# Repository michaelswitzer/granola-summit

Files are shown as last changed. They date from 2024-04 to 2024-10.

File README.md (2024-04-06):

# Summit by Granola Arcade

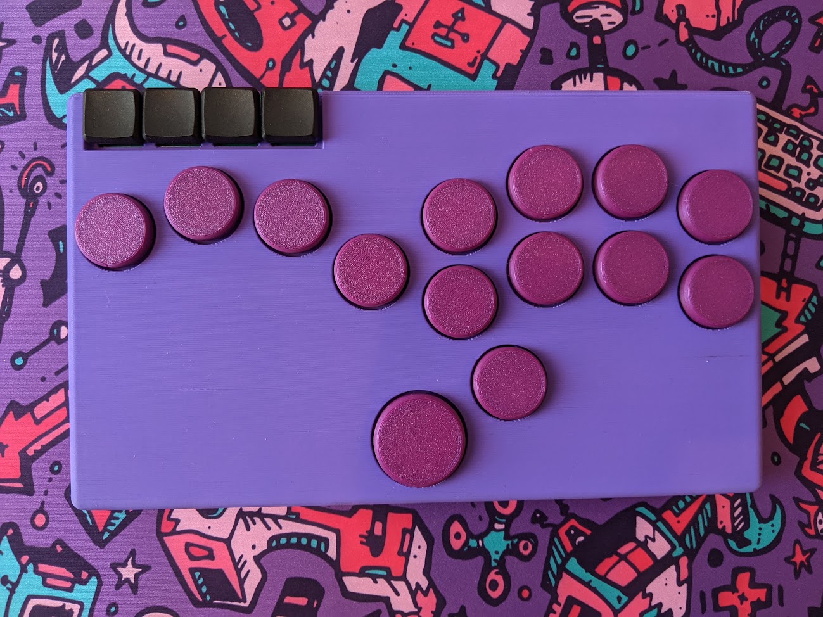
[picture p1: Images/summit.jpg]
Summit fightstick


The Summit is a button box style arcade controller by Granola Arcade.

You can buy the Summit at https://granola.games

## License
The Raindrop is licensed under a <a rel="license" href="http://creativecommons.org/licenses/by-nc-sa/4.0/">Creative Commons Attribution-NonCommercial-ShareAlike 4.0 International License</a>. In simple terms, this means you are welcome to use or remix these designs to build your own controller free of cost. You are *not* permitted to sell the Summit commercially. You also can't republish the designs without attribution and without carrying this license forward into your new designs. For more information see the license file in this repository.

## How to build
To build your own Summit, import the PCB designs and bill of materials using KiCAD. I provided a list of parts that use JLCPCB's part assembly services, since that is the company I use to manufacture the PCB. You can use these files as a starting point for building your own PCB.

The .step file for the case is optimized for FDM 3D printers. I recommend PLA with at least 15% infill but you can use any material you wish. The case has designed break-away supports that you will remove after printing. It should already be aligned in the correct orientation.

The keycap files are also included, for use with Kailh Choc V2 stems (MX style). You may need to adjust the x-y hole and contour compensation values in your slicer for proper fitment.

You will need to source your own key switches. The Summit uses Kailh low-profile Choc keyboard switches.

Once you have the case, switches and keycaps, you simply slide the PCB into the top of the case and then attach the switches and keycaps to assemble. Then plug the controller into your PC and upload the firmware.

## Firmware
The Summit is designed to use the <a rel="GP2040-CE firmware" href="https://github.com/OpenStickCommunity/GP2040-CE">GP2040-CE firmware</a>.

## Credits
The Raindrop was designed by Michael Switzer. The GP2040-CE firmware is maintained by <a href="https://github.com/OpenStickCommunity">OpenStickCommunity</a>. This project was inspired by the <a href="https://github.com/jfedor2/flatbox">Flatbox</a>.

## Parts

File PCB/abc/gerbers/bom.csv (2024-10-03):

Comment | Designator | Footprint | LCSC Part Number
10uF | C1,C2 | Capacitor_SMD:C_0805_2012Metric | C83061
27p | C3,C4 | Capacitor_SMD:C_0402_1005Metric | C147436
100nF | C5,C6,C7,C9,C11,C12,C13,C14,C15,C16 | Capacitor_SMD:C_0402_1005Metric | C361203
1uF | C8,C10 | Capacitor_SMD:C_0402_1005Metric | C5137485
10uF | C17 | Capacitor_SMD:C_0805_2012Metric | C83061
HRO-TYPE-C-31-M-12 | USB1 | Type-C:HRO-TYPE-C-31-M-12-Assembly | C165948
USB_A | USB2 | USB-A-SMD_C42591 | C42591
1k | R1,R4 | Capacitor_SMD:C_0402_1005Metric | C105637
5.1k | R5,R6 | Resistor_SMD:R_0402_1005Metric | C25905
27 ohm | R2,R3 | Capacitor_SMD:C_0402_1005Metric | C2909343
TS-1187A-B-A-B | SW1 | Button_Switch_SMD:SW_Push_1P1T_XKB_TS-1187A | C318884
MX_Switch | SW2,SW3,SW4,SW5,SW6,SW7,SW8,SW9,SW10,SW11,SW12,SW13,SW14,SW15,SW16,SW17,SW18,SW19 | Kailh:SW_Hotswap_Kailh_Choc_V1V2_1.00u_reversible,Kailh:SW_Hotswap_Kailh_Choc_V1V2_1.00u_24mm_reversible,Kailh:SW_Hotswap_Kailh_Choc_V1V2_1.00u_30mm_reversible | C5333465
AMS1117 | U1 | Package_TO_SOT_SMD:SOT-223-3_TabPin2 | C5250992
W25Q128JVS | U2 | Package_SO:SOIC-8_5.23x5.23mm_P1.27mm | C97521
RP2040 | U3 | RP2040_minimal:RP2040-QFN-56 | C2040
USBLC6-2SC6 | U4 | Package_TO_SOT_SMD:SOT-23-6 | C5250994
Crystal_GND24 | Y1 | Crystal:Crystal_SMD_3225-4Pin_3.2x2.5mm | C9002
AudioJack3 | J1,J2,J3 | Connector_Audio:Jack_3.5mm_PJ320D_Horizontal | C431535

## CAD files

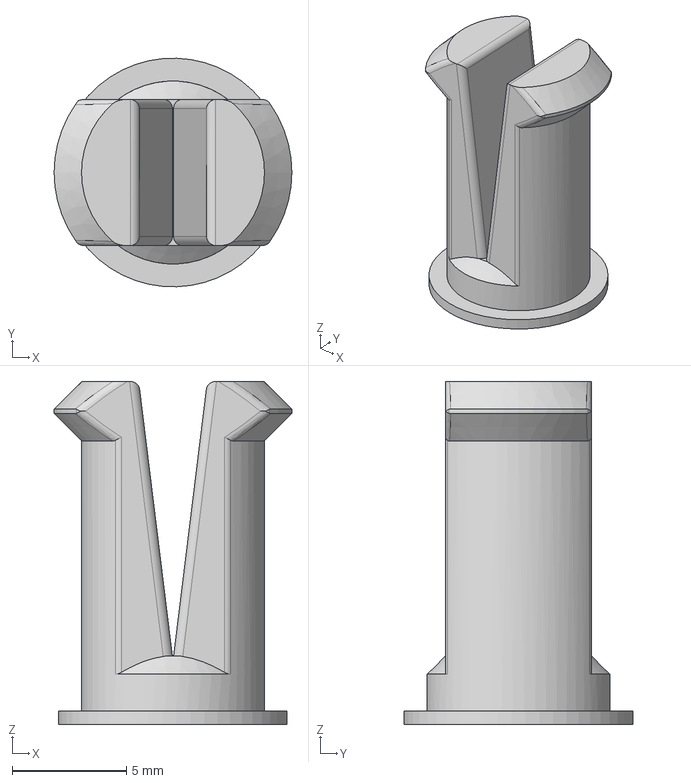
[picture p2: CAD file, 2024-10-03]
Printer/ArtCase-peg.step
10.4 x 10.00 x 15.0 mm

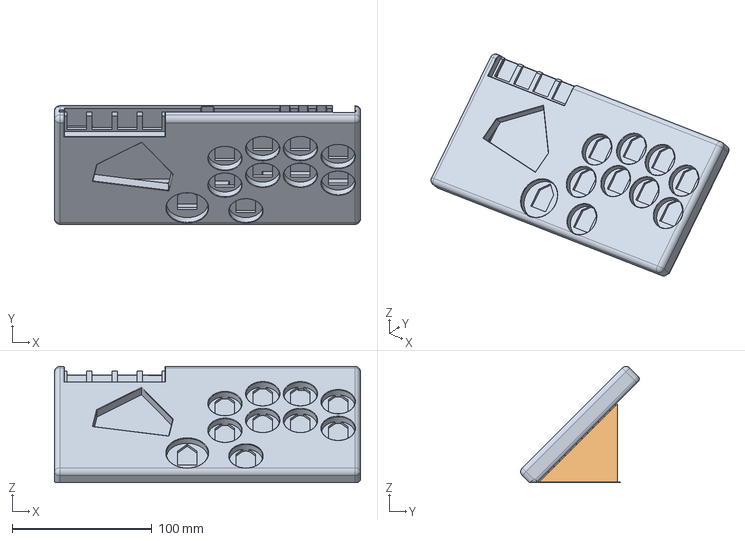
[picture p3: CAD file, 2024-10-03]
Printer/Wasd-case.step
219.0 x 84.9 x 83.2 mm

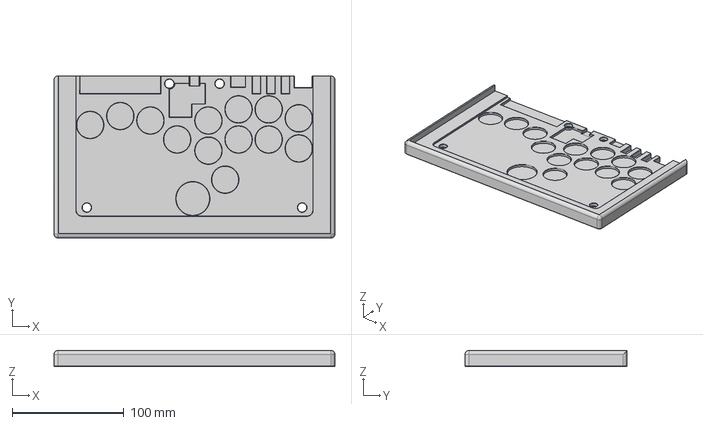
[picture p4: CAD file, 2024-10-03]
Printer/ArtCase-case.step
251.8 x 145.4 x 14.4 mm

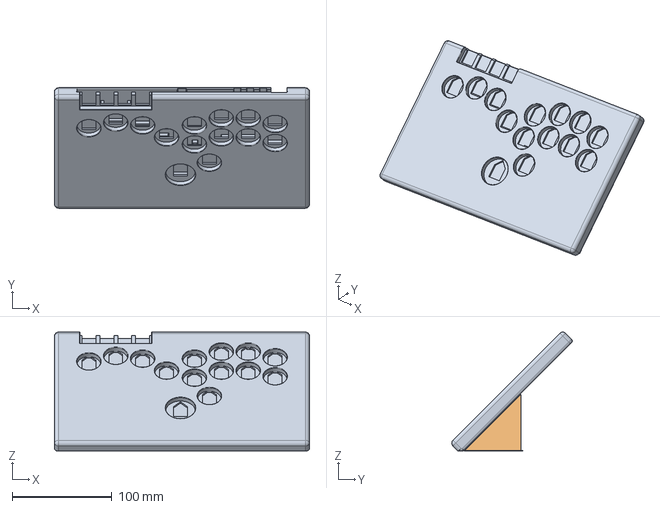
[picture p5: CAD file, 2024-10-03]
Printer/Summit-big-case.step
256.0 x 121.0 x 119.3 mm

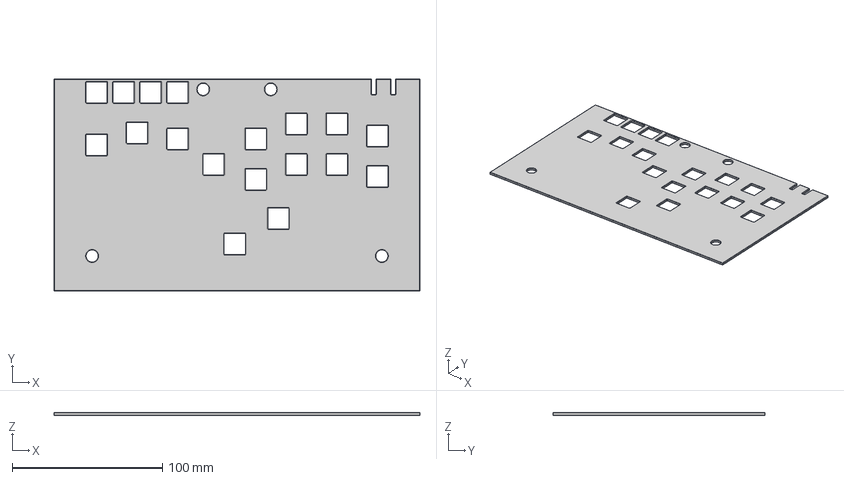
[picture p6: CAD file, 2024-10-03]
Printer/ArtCase-plate.step
243.8 x 141.4 x 2.00 mm

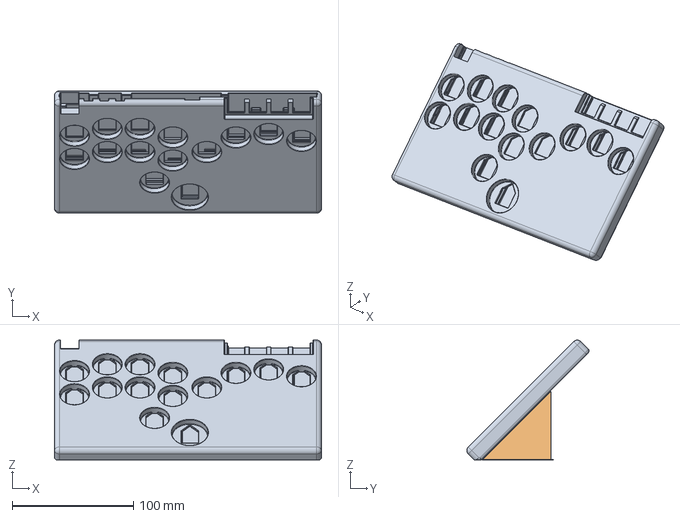
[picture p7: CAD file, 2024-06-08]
Printer/Southpaw-Summit-case.step
220.0 x 100.7 x 98.7 mm

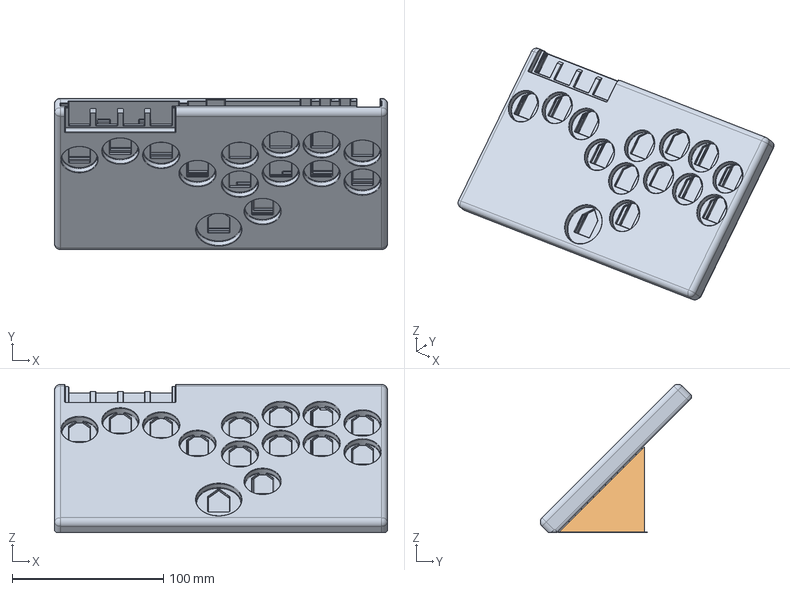
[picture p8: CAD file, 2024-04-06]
Printer/Summit-case.step
220.0 x 100.0 x 98.0 mm

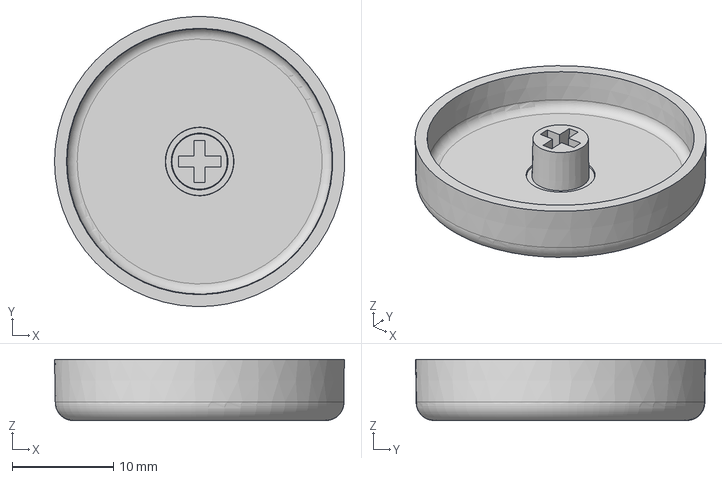
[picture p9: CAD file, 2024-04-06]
Printer/ButtonCap-30mm.step
28.6 x 28.6 x 6.02 mm

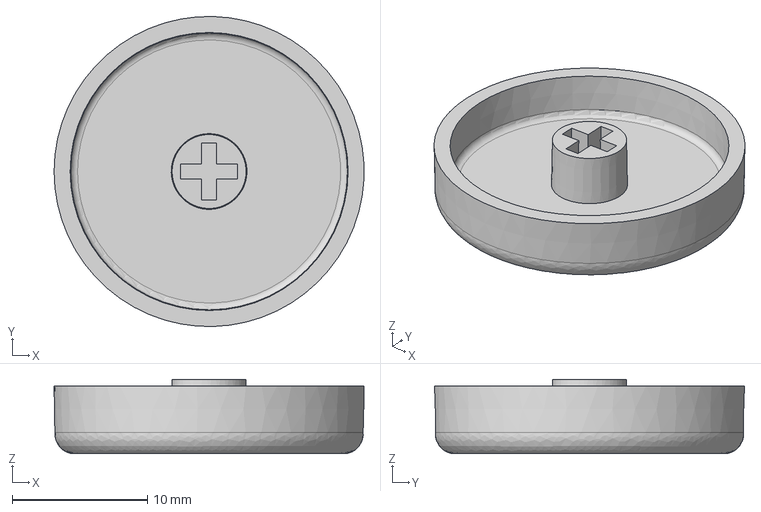
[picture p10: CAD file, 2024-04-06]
Printer/ButtonCap-24mm.step
22.9 x 22.9 x 5.50 mm

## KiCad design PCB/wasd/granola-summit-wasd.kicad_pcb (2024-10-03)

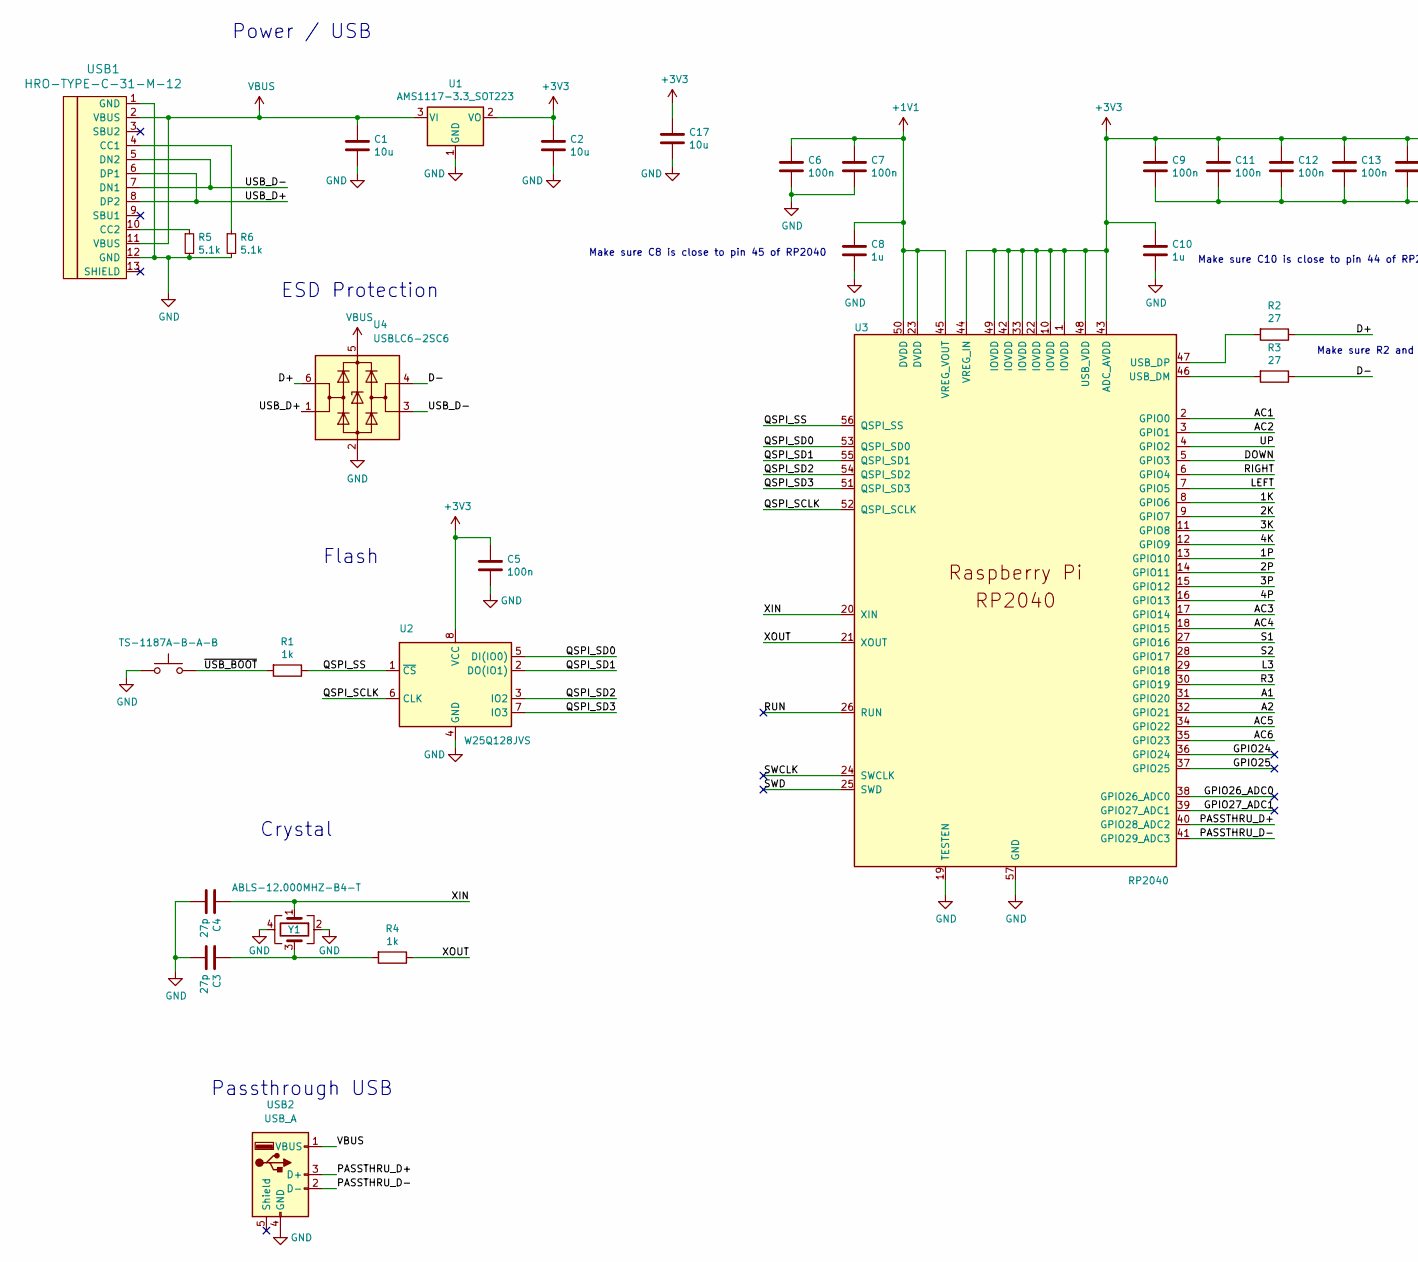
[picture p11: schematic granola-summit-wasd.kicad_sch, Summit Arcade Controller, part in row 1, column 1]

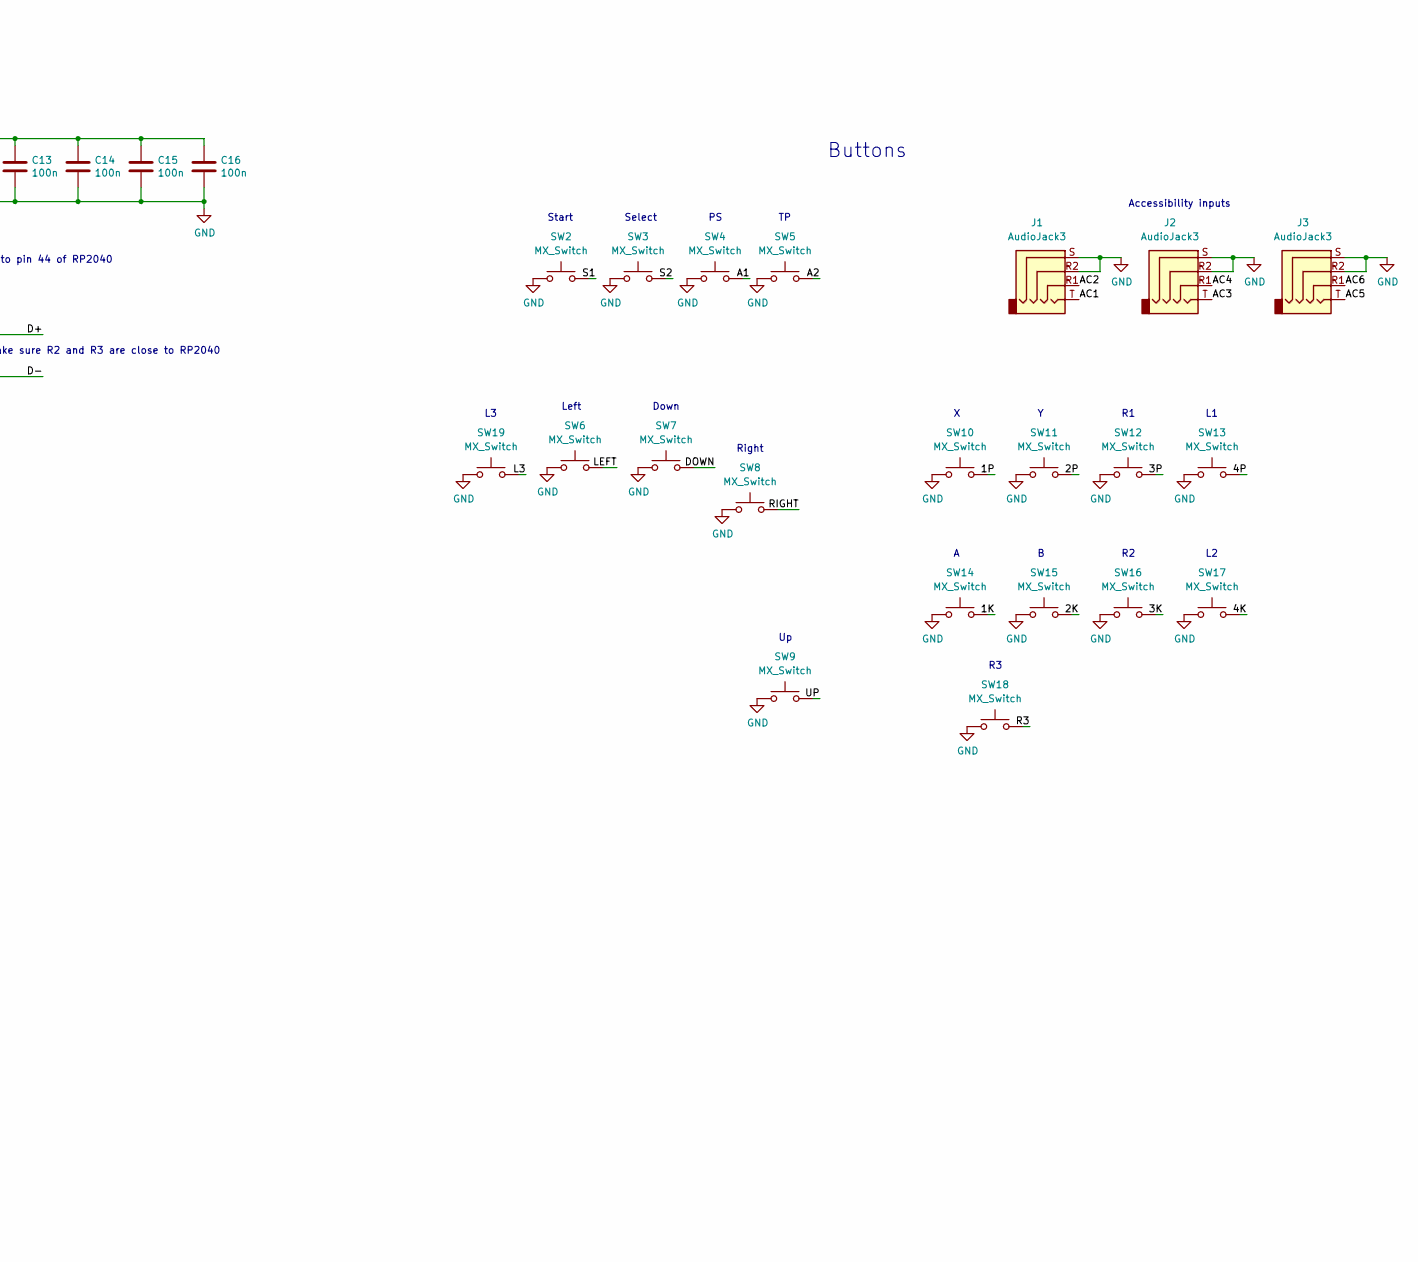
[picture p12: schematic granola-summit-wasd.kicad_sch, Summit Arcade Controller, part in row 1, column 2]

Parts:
C1, C2, C17: 10u; C_0805_2012Metric; LCSC C83061
C3, C4: 27p; C_0402_1005Metric; LCSC C147436
C5, C6, C7, C9, C11, C12, C13, C14, C15, C16: 100n; C_0402_1005Metric; LCSC C115671
C8, C10: 1u; C_0402_1005Metric; LCSC C5137485
J1, J2, J3: AudioJack3; Jack_3.5mm_PJ320D_Horizontal
R1, R4: 1k; C_0402_1005Metric; LCSC C105637
R2, R3: 27; C_0402_1005Metric; LCSC C2909343
R5, R6: 5.1k; R_0402_1005Metric; LCSC C25905
SW1: TS-1187A-B-A-B; SW_Push_1P1T_XKB_TS-1187A; LCSC C318884
SW2, SW3, SW4, SW5, SW6, SW7, SW8, SW9, SW10, SW11, SW12, SW13, SW14, SW15, SW16, SW17, SW18, SW19: MX_Switch; SW_Hotswap_Kailh_Choc_V1V2_1.00u
U1: AMS1117-3.3_SOT223; SOT-223-3_TabPin2; LCSC C5250992
U2: W25Q128JVS; SOIC-8_5.23x5.23mm_P1.27mm; LCSC C97521
U3: RP2040; RP2040-QFN-56; LCSC C2040
U4: USBLC6-2SC6; SOT-23-6
USB1: HRO-TYPE-C-31-M-12; HRO-TYPE-C-31-M-12-Assembly; LCSC C165948
USB2: USB_A; USB-A-SMD_C42591; LCSC C42591
Y1: ABLS-12.000MHZ-B4-T; Crystal_SMD_3225-4Pin_3.2x2.5mm; LCSC C9002

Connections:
+1V1: C6.1, C7.1, C8.1, U3.23 (DVDD), U3.45 (VREG_VOUT), U3.50 (DVDD)
+3V3: C2.1, C5.1, C9.1, C10.1, C11.1, C12.1, C13.1, C14.1, C15.1, C16.1, C17.1, U1.2 (VO), U2.8 (VCC), U3.1 (IOVDD), U3.10 (IOVDD), U3.22 (IOVDD), U3.33 (IOVDD), U3.42 (IOVDD), U3.43 (ADC_AVDD), U3.44 (VREG_IN), U3.48 (USB_VDD), U3.49 (IOVDD)
/1K: SW14.1 (A), U3.8 (GPIO6)
/1P: SW10.1 (A), U3.13 (GPIO10)
/2K: SW15.1 (A), U3.9 (GPIO7)
/2P: SW11.1 (A), U3.14 (GPIO11)
/3K: SW16.1 (A), U3.11 (GPIO8)
/3P: SW12.1 (A), U3.15 (GPIO12)
/4K: SW17.1 (A), U3.12 (GPIO9)
/4P: SW13.1 (A), U3.16 (GPIO13)
/A1: SW4.1 (A), U3.31 (GPIO20)
/A2: SW5.1 (A), U3.32 (GPIO21)
/AC1: J1.T, U3.2 (GPIO0)
/AC2: J1.R1, U3.3 (GPIO1)
/AC3: J2.T, U3.17 (GPIO14)
/AC4: J2.R1, U3.18 (GPIO15)
/AC5: J3.T, U3.34 (GPIO22)
/AC6: J3.R1, U3.35 (GPIO23)
/D+: R2.1, U4.6 (I/O1)
/D-: R3.1, U4.4 (I/O2)
/DOWN: SW7.1 (A), U3.5 (GPIO3)
/GPIO24: U3.36 (GPIO24)
/GPIO25: U3.37 (GPIO25)
/GPIO26_ADC0: U3.38 (GPIO26_ADC0)
/GPIO27_ADC1: U3.39 (GPIO27_ADC1)
/L3: SW19.1 (A), U3.29 (GPIO18)
/LEFT: SW6.1 (A), U3.7 (GPIO5)
/PASSTHRU_D+: U3.40 (GPIO28_ADC2), USB2.3 (D+)
/PASSTHRU_D-: U3.41 (GPIO29_ADC3), USB2.2 (D-)
/QSPI_SCLK: U2.6 (CLK), U3.52 (QSPI_SCLK)
/QSPI_SD0: U2.5 (DI(IO0)), U3.53 (QSPI_SD0)
/QSPI_SD1: U2.2 (DO(IO1)), U3.55 (QSPI_SD1)
/QSPI_SD2: U2.3 (IO2), U3.54 (QSPI_SD2)
/QSPI_SD3: U2.7 (IO3), U3.51 (QSPI_SD3)
/QSPI_SS: R1.1, U2.1 (~CS), U3.56 (QSPI_SS)
/R3: SW18.1 (A), U3.30 (GPIO19)
/RIGHT: SW8.1 (A), U3.6 (GPIO4)
/RUN: U3.26 (RUN)
/S1: SW2.1 (A), U3.27 (GPIO16)
/S2: SW3.1 (A), U3.28 (GPIO17)
/SWCLK: U3.24 (SWCLK)
/SWD: U3.25 (SWD)
/UP: SW9.1 (A), U3.4 (GPIO2)
/USB_D+: U4.1 (I/O1), USB1.6 (DP1), USB1.8 (DP2)
/USB_D-: U4.3 (I/O2), USB1.5 (DN2), USB1.7 (DN1)
/XIN: C4.1, U3.20 (XIN), Y1.1
/XOUT: R4.1, U3.21 (XOUT)
/~USB_BOOT: R1.2, SW1.1
GND: C1.2, C2.2, C3.2, C4.2, C5.2, C6.2, C7.2, C8.2, C9.2, C10.2, C11.2, C12.2, C13.2, C14.2, C15.2, C16.2, C17.2, J1.R2, J1.S, J2.R2, J2.S, J3.R2, J3.S, R5.2, R6.2, SW1.2, SW2.2 (B), SW3.2 (B), SW4.2 (B), SW5.2 (B), SW6.2 (B), SW7.2 (B), SW8.2 (B), SW9.2 (B), SW10.2 (B), SW11.2 (B), SW12.2 (B), SW13.2 (B), SW14.2 (B), SW15.2 (B), SW16.2 (B), SW17.2 (B), SW18.2 (B), SW19.2 (B), U1.1 (GND), U2.4 (GND), U3.19 (TESTEN), U3.57 (GND), U4.2 (GND), USB1.1 (GND), USB1.12 (GND), USB2.4 (GND), Y1.2, Y1.4
unnamed: C3.1, R4.2, Y1.3
unnamed: R3.2, U3.46 (USB_DM)
unnamed: R2.2, U3.47 (USB_DP)
unnamed: R6.1, USB1.4 (CC1)
unnamed: R5.1, USB1.10 (CC2)
VBUS: C1.1, U1.3 (VI), U4.5 (VBUS), USB1.2 (VBUS), USB1.11 (VBUS), USB2.1 (VBUS)

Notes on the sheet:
ESD Protection
Right
Start
Down
Left
Make sure R2 and R3 are close to RP2040
Crystal
Passthrough USB
Make sure C10 is close to pin 44 of RP2040
Flash
Accessibility inputs
Power / USB
Select
Buttons
Make sure C8 is close to pin 45 of RP2040

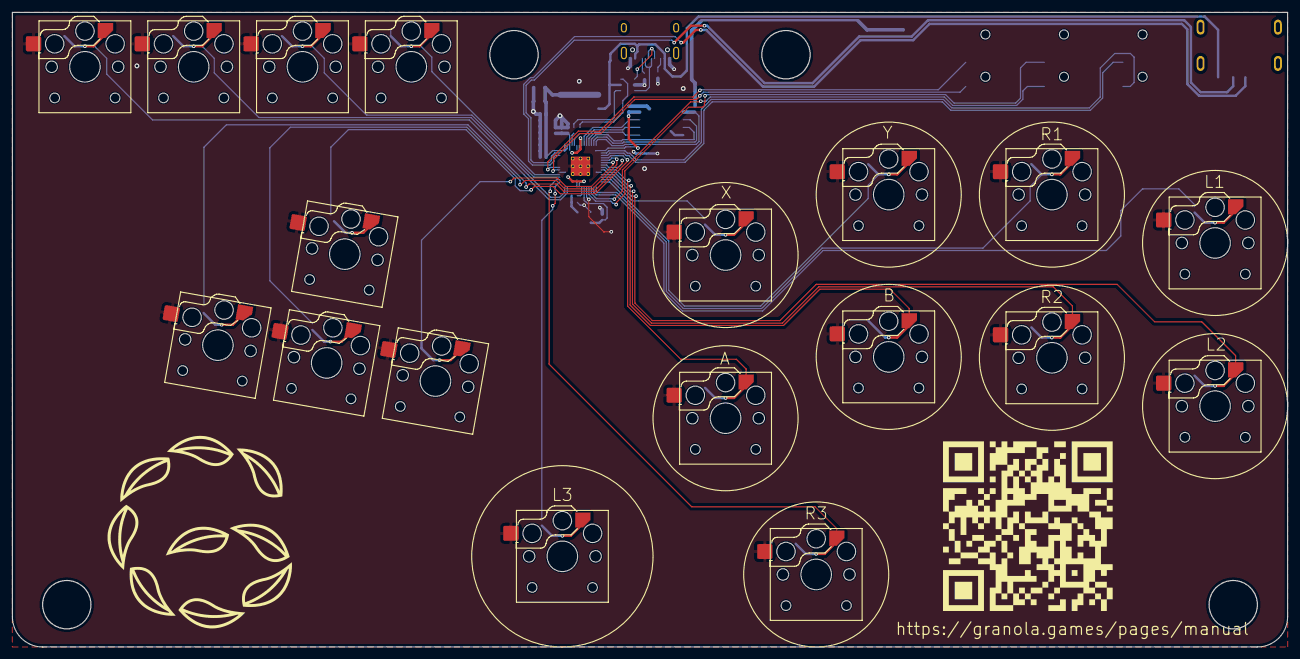
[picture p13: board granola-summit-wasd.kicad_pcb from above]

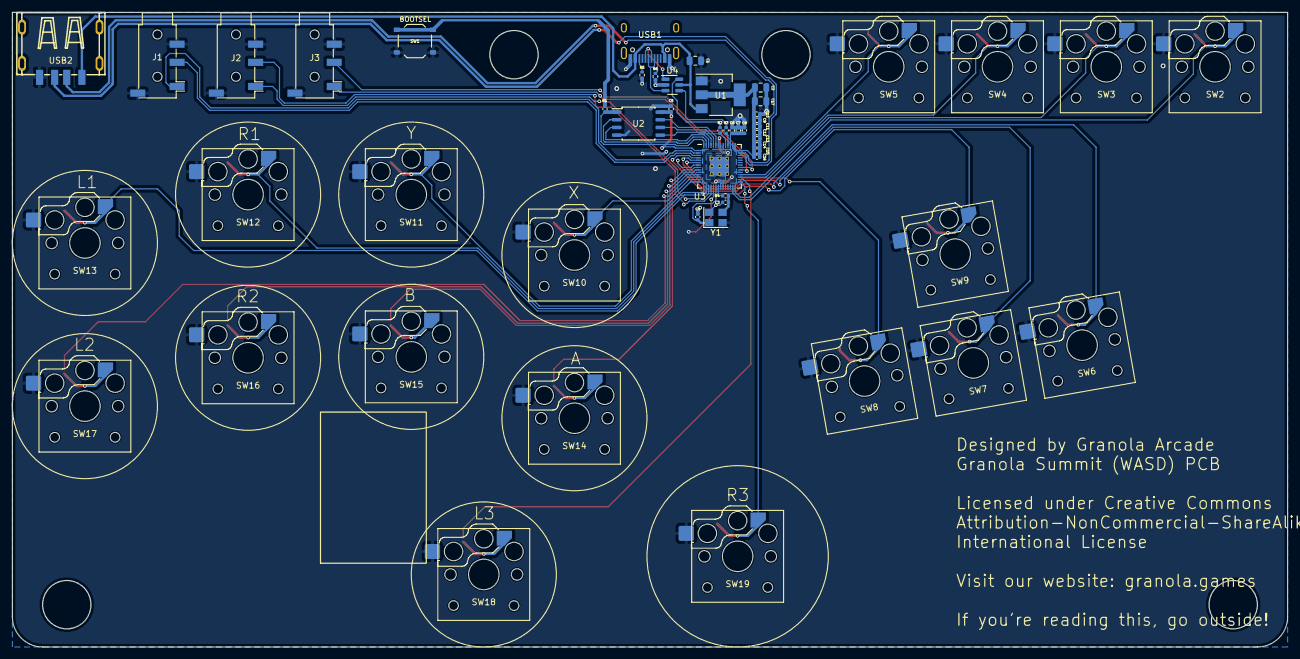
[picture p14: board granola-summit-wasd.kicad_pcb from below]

Board: 2 copper layers, 211.0 x 105.0 mm, 52 parts (52 on the bottom side), 48 nets.

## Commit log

2024-06-08 Added southpaw and big summit cases. +1mm thickness to original case.
    [Big-Summit-case.step, Southpaw-Summit-case.step, Summit-case.step]
2024-10-03 v2.0 board design, WASD model
    [ArtCase-case.step, ArtCase-peg.step, ArtCase-plate.step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]

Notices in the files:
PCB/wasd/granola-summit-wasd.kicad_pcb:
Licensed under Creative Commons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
